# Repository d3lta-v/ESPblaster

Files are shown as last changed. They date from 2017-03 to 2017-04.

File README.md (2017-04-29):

# ESPblaster

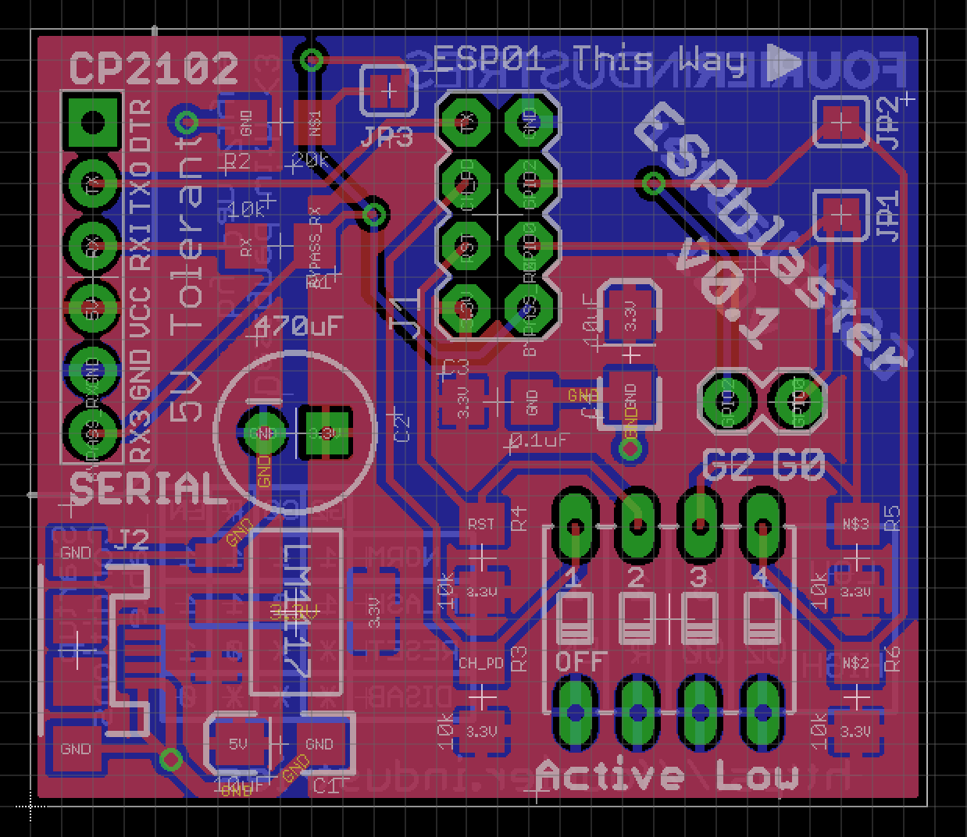
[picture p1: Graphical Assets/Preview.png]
PCB Preview


Designed by [FourierIndustries](https://fourier.industries) by Pan Ziyue

## Overview
The ESPblaster is a simple and straightforward ESP8266-01 flashing device, with onboard logic level translation, high stability voltage regulation, and an active-low DIP switch to toggle the ESP8266-01 module's startup states. All of the components are either through-hole or 1206 SMD, which makes the board easily solderable. JP1, JP2 and JP3 are jumpers on the board that should be closed by default with a solder blob. This circuit board provides a quick and easy alternative to flashing or interacting with the ESP8266-01 module without complicated breadboarding. 

## Interface
The ESPblaster has a 6-pin serial interface:

* **DTR** (not wired to anything)
* **TXO** (Transmit Out) [5V compliant]
* **RXI** (Receive In) [5V compliant]
* **VCC** (5V in)
* **GND**
* **RX3** (Receive In) [3.3V compliant]

## DIP switches
The ESPblaster packs a DIP switch to alter the startup states, as well as reset the module or disable the module. 

#### Warning: the DIP switch is an active low switch! This means that flipping the switch up to "On" will pull low the circuit!

The DIP switches are responsible for the following states (from left to right, from the front face of the board):

1. **CH_PD** (Chip Enable)
2. **RST** (Reset)
3. **GPIO0**
4. **GPIO2**

## Startup states table

| | CH_PD | RST | GPIO0 | GPIO2 |
|---|:-----:|:---:|:-----:|:-----:|
| Normal Startup | 1 |  1  | 1 | 1 |
| Flash bootloader | 1 |  1  | 0 | 1 |
| Reset | 1 |  0  | X | X |
| Disable | 0 |  X  | X | X |

## Solder blob jumpers
JP1, JP2 and JP3 are solder blob jumpers, which should be closed by default. They are responsible for the following:

* **JP1**: Connects GPIO0 to the DIP switch
* **JP2**: Connects GPIO2 to the DIP switch
* **JP3**: When connected, the RXI signal will pass through the logic level shifter and if disconnected, you must use the RX3 pin to supply 3.3V logic for the RX of the ESP8266-01.

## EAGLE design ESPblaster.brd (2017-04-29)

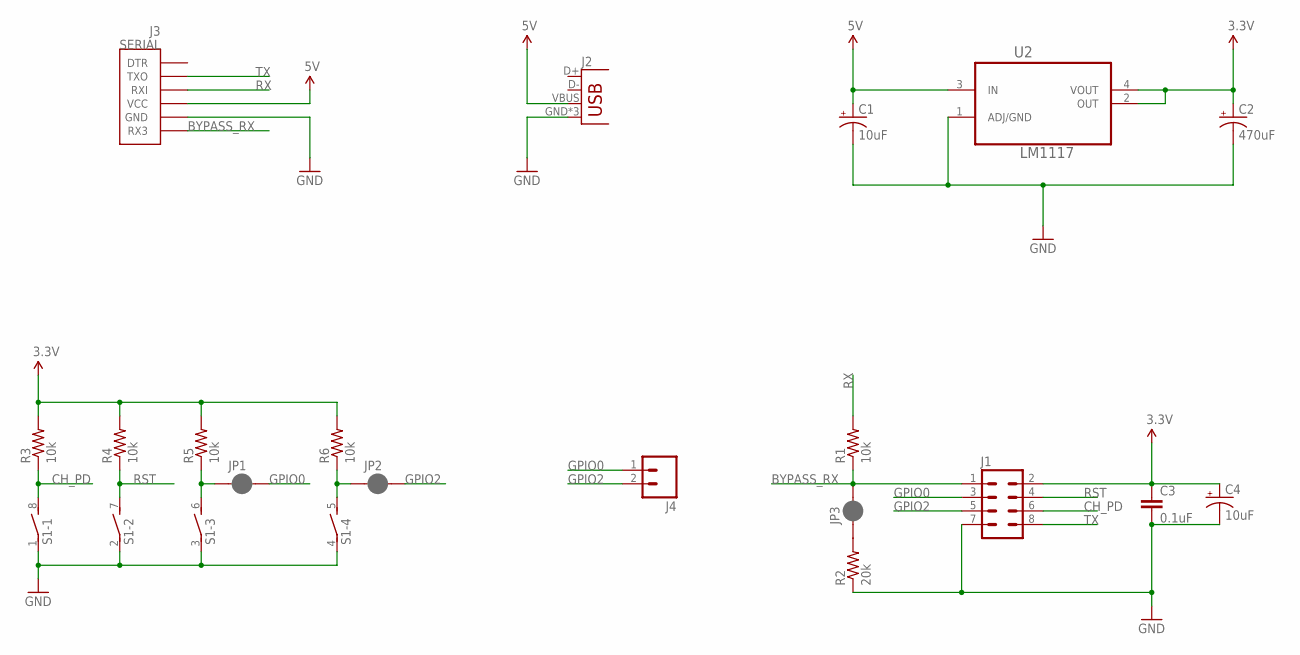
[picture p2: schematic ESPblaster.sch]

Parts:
C1, C4: 10uF; EIA3216-KIT
C2: 470uF; CPOL-RADIAL-100UF-25V
C3: 0.1uF; 1206
J1: M04X2; 2X4
J2: USB-MICROB
J3: SERIAL; CP2102_DEVICE_SIDE_ESP8266
J4: M02LOCK; 1X02_LOCK
JP1, JP2, JP3: JUMPER-PAD-2-NC_BY_PASTEFULL-BOX-SILK; PAD-JUMPER-2-NC_BY_PASTE_YES_SILK_FULL_BOX
R1, R3, R4, R5, R6: 10k; 1206
R2: 20k; 1206
S1: DIP04S
U2: LM1117; SOT230P696X180-4N

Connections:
3.3V: C2.1 (+), C3.1, C4.A (+), J1.2, R3.2, R4.2, R5.2, R6.2, U2.2 (OUT), U2.4 (VOUT)
5V: C1.A (+), J2.VBUS, J3.P$4 (VCC), U2.3 (IN)
BYPASS_RX: J1.1, J3.P$6 (RX3), JP3.2, R1.1
CH_PD: J1.6, R3.1, S1.8 (2)
GND: C1.C (-), C2.2 (-), C3.2, C4.C (-), J1.7, J2.GND, J2.MT1 (GND), J2.MT2 (GND), J3.P$5 (GND), R2.1, S1.1, S1.2 (1), S1.3 (1), S1.4 (1), U2.1 (ADJ/GND)
GPIO0: J1.3, J4.1, JP1.2
GPIO2: J1.5, J4.2, JP2.2
unnamed: JP3.1, R2.2
unnamed: JP2.1, R6.1, S1.5 (2)
unnamed: JP1.1, R5.1, S1.6 (2)
RST: J1.4, R4.1, S1.7 (2)
RX: J3.P$3 (RXI), R1.2
TX: J1.8, J3.P$2 (TXO)

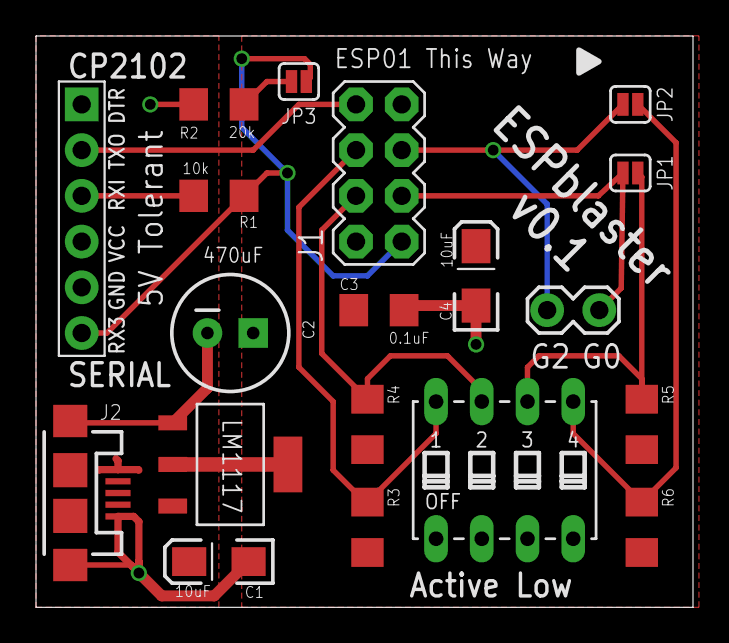
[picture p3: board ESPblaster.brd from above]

Board: 2 copper layers, 36.5 x 31.7 mm, 20 parts (0 on the bottom side), 13 nets.

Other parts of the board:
U$1: FOURIERINDUSTRIES-SMALL-INV

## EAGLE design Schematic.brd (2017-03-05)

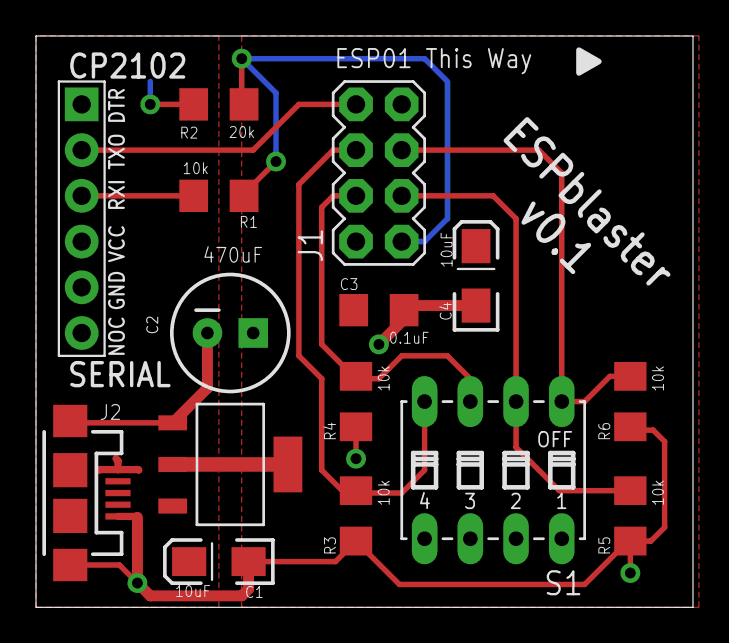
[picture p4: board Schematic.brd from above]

Board: 2 copper layers, 36.5 x 31.7 mm, 16 parts (0 on the bottom side), 10 nets.

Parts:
C1, C4: 10uF; EIA3216-KIT
C2: 470uF; CPOL-RADIAL-100UF-25V
C3: 0.1uF; 1206
J1: 2X4
J2: USB-MICROB
J3: SERIAL; CP2102_DEVICE_SIDE
R1, R3, R4, R5, R6: 10k; 1206
R2: 20k; 1206
S1: DIP04S
U2: LM1117; SOT230P696X180-4N
U$1: FOURIERINDUSTRIES-SMALL-INV

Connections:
3.3V: C2.1, C3.1, C4.A, J1.2, S1.5, S1.6, S1.7, S1.8, U2.2, U2.4
5V: C1.A, J2.VBUS, J3.P$4, U2.3
CH_PD: J1.6, R3.2, S1.4
GND: C1.C, C2.2, C3.2, C4.C, J1.7, J2.GND, J2.MT1, J2.MT2, J3.P$5, R2.1, R3.1, R4.1, R5.1, R6.1, U2.1
GPIO0: J1.3, R5.2, S1.2
GPIO2: J1.5, R6.2, S1.1
unnamed: J1.1, R1.1, R2.2
RST: J1.4, R4.2, S1.3
RX: J3.P$3, R1.2
TX: J1.8, J3.P$2

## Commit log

2017-03-05 Added some styling
    [Schematic.brd]
2017-03-05 Cleaned up text positions
    [Schematic.brd, Schematic.sch]
2017-03-05 Reorganised folders
    [Schematic.brd, Schematic.sch]
2017-03-06 Redesigned switches to pull HIGH, added truth table, cuttable jumper for G2 and G0
2017-03-06 Added logic high and low silkscreen
    [Schematic.brd]
2017-03-06 Fixed orientation of DIP switch
    [Schematic.brd, Schematic.sch]
2017-03-06 final edits
    [Schematic.brd]
2017-04-29 Rearranged files and added image preview
    [ESPblaster.brd, ESPblaster.sch, Schematic.sch]

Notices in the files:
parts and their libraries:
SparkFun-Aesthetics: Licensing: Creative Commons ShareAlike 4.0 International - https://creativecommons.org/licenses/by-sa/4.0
